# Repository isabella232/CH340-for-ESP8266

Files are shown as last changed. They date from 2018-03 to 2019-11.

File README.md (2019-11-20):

# USB-Serial converter for ESP8266 auto program

DTR, RTS を利用して ESP8266(ESP-WROOM-02) のリセットを制御。Arduino での書き込みを自動化する。

はんだごてでハンダづけでき、わりかしコンパクトなフットプリント。

3.3V 専用。

`J1` ピンはショットキーバリアダイオードを通る分、5V から電圧降下(0.3～0.4V)します。

# ボード

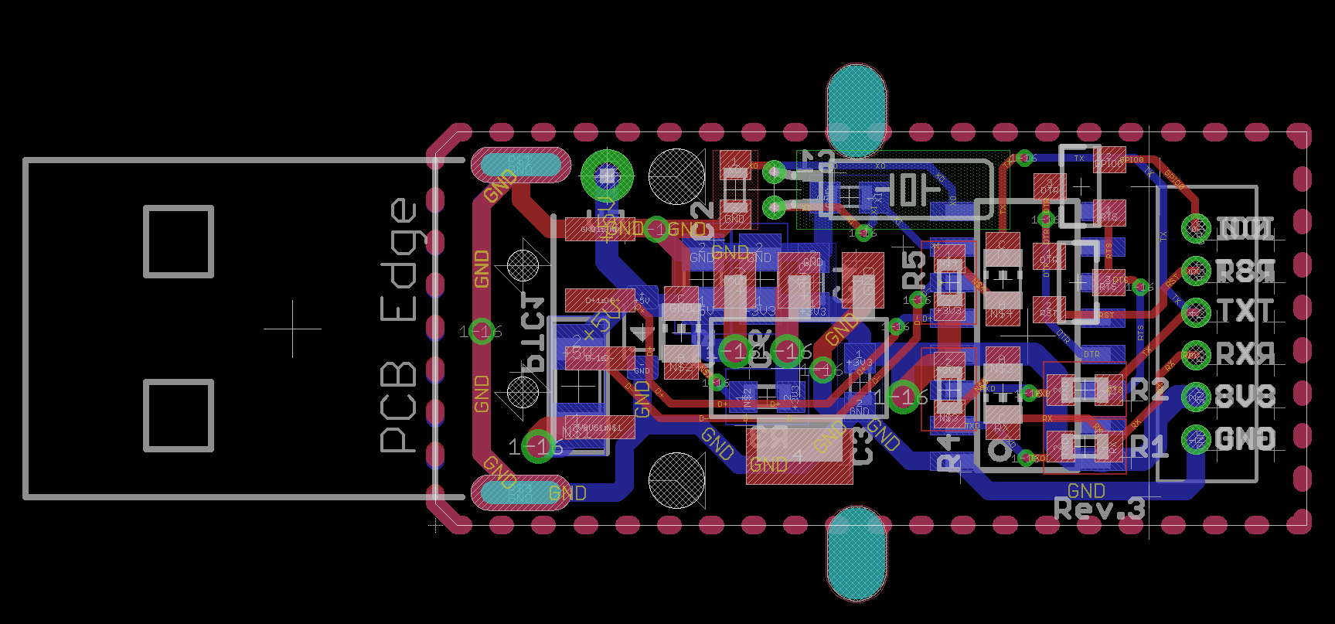
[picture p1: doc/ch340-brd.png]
brd


# 回路図

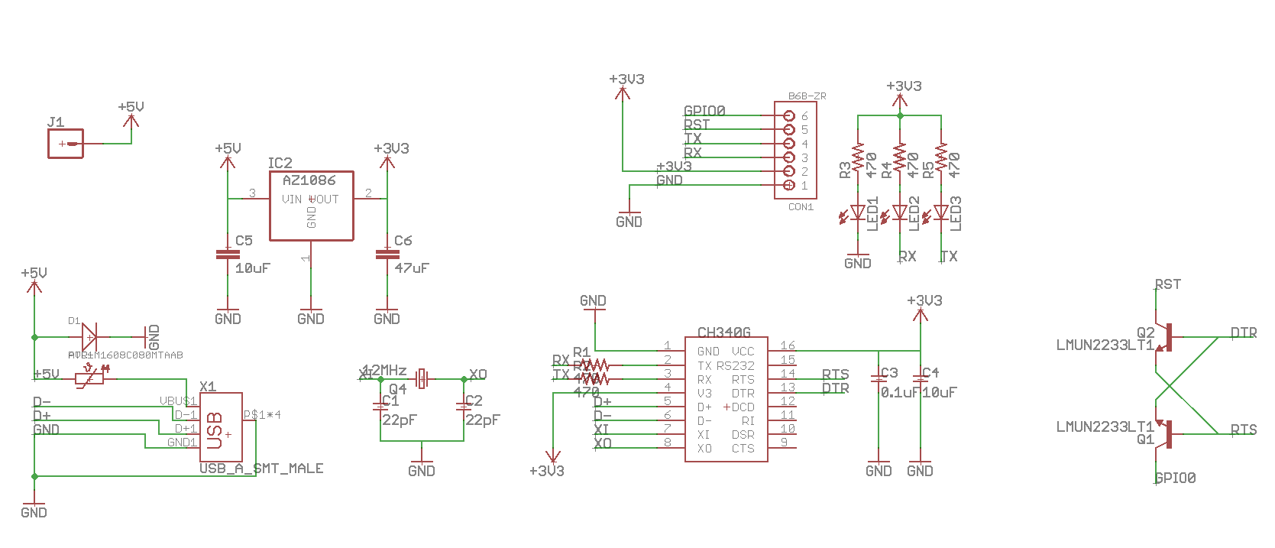
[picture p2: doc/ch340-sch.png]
sch


# 部品表

| 部品番号 | 値 | 部品名 | 入手先 | 備考 |
| --- | --- | --- | --- | --- |
| D1 | 30V1A | ショットキーバリアダイオード RSX101VAM-30TR | 秋月電子 | [I-05951](http://akizukidenshi.com/catalog/g/gI-05951/) |
| PTC1 | 0.75A6V(2012) | リセッタブルフューズ PICOSMDC075S-2 | eBay | https://www.ebay.com/itm/263051781459 |
| X1 | | USBコネクタ(A/オス) UAM-21BK | aitendo  | http://www.aitendo.com/product/16665 |
| C1/C2 | 22pF50V(1608) | 積セラコンデンサ | aitendo  | http://www.aitendo.com/product/6989 |
| Q4 | 12MHz | クリスタル（2x6） | aitendo  | http://www.aitendo.com/product/5028 |
| C3 | 0.1uF50V(1608) | 積セラコンデンサ GRM188F11H104ZA01 | 秋月電子 | [P-13374](http://akizukidenshi.com/catalog/g/gP-13374/) |
| C4/C5 | 10uF25V(2012) | 積セラコンデンサ GRM21BB31E106KA | 秋月電子 | [P-13388](http://akizukidenshi.com/catalog/g/gP-13388/) |
| IC1 | | USB-シリアルコンバータ CH340G | aitendo  | http://www.aitendo.com/product/11576 |
| C6 | 22uF25V(1608) | 積セラコンデンサ GRM21BR61E226ME44 | 秋月電子 | [P-08240](http://akizukidenshi.com/catalog/g/gP-08240/) 47uF がいいかも [mouser](https://www.mouser.jp/Passive-Components/Capacitors/Ceramic-Capacitors/MLCCs-Multilayer-Ceramic-Capacitors/Multilayer-Ceramic-Capacitors-MLCC-SMD-SMT/_/N-bkrdv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) |
| IC2 | 3.3V | レギュレータ AMS1117-3.3 や AZ1086H-3.3 | 秋月電子 | [I-02502](http://akizukidenshi.com/catalog/g/gI-02502/) |
| R1/R2/R3/R4/R5 | 470Ω(1608) | チップ抵抗 | 千石電商 | https://www.sengoku.co.jp/mod/sgk_cart/detail.php?code=EEHD-57GC |
| LED1 | VF=1.9～2.1V(1608) | オレンジ色チップLED | 秋月電子 | [I-06416](http://akizukidenshi.com/catalog/g/gI-06416/) |
| LED2 | VF=1.9～2.1V(1608) | 黄緑色チップLED | 秋月電子 | [I-03980](http://akizukidenshi.com/catalog/g/gI-03980) |
| LED3 | VF=1.9～2.1V(1608) | 赤色チップLED | 秋月電子 | [I-03978](http://akizukidenshi.com/catalog/g/gI-03978) |
| CON1 | ZHコネクタ6ピン | S6B-ZR | 秋月電子 | [C-14164](http://akizukidenshi.com/catalog/g/gC-14164/) ワイヤ直付けでもよいと思います |
| Q1/Q2 | | LMUN2233LT1G | eBay | https://www.ebay.com/itm/262770111020 |
| | E40X18.5X9.6B | USBプラケース | aitendo  | http://www.aitendo.com/product/16537 |

# できあがり

## 表面

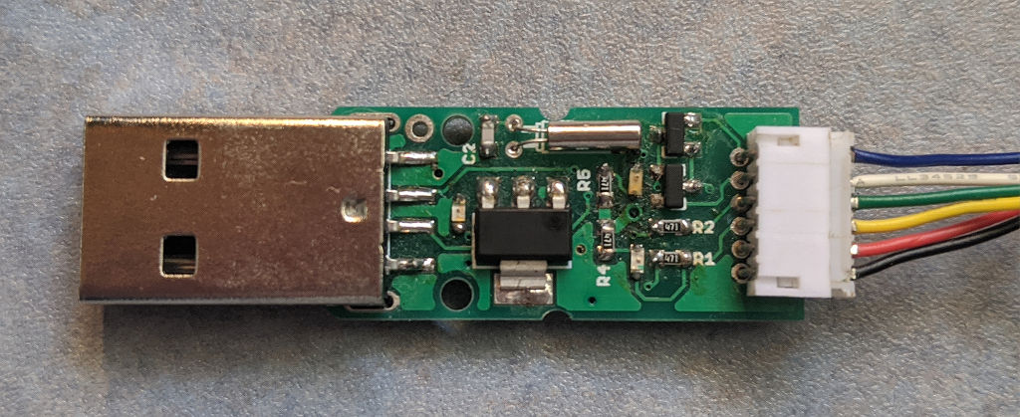
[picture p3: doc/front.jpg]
front


## 裏面

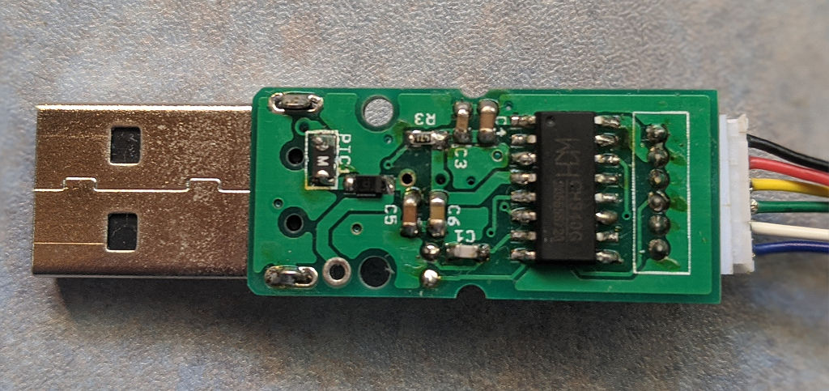
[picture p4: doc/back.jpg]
back


## ケースに入れて接続した状態

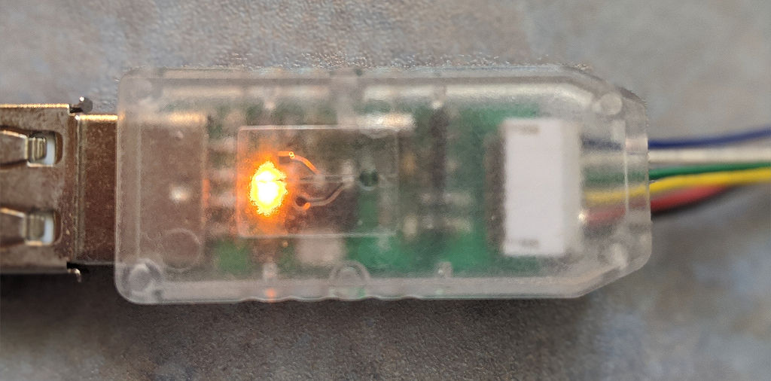
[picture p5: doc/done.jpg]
done


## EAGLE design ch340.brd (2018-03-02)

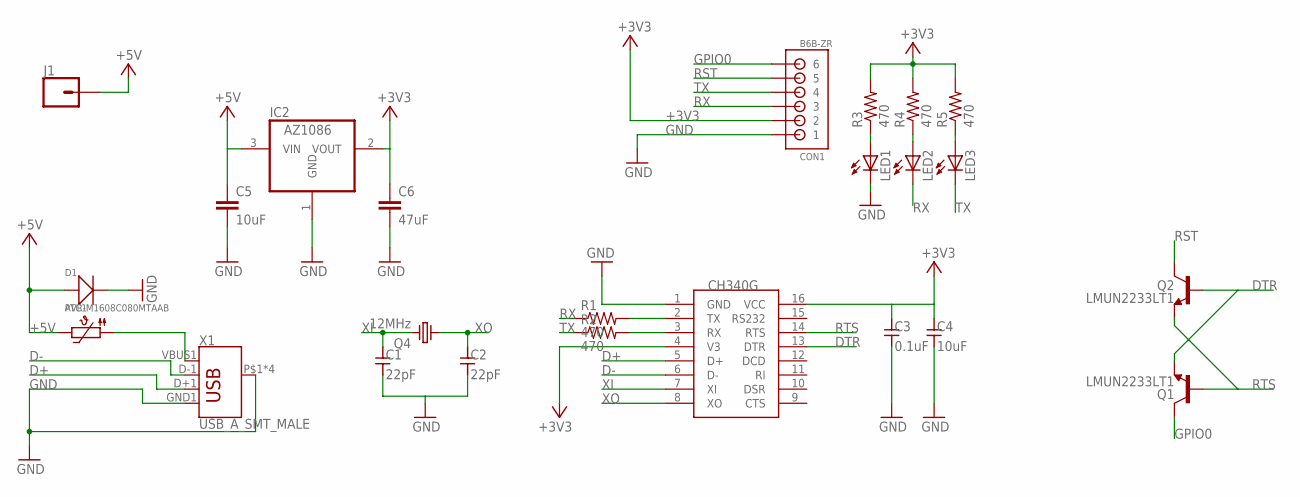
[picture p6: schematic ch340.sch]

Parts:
C1, C2: 22pF; SMD1608
C3: 0.1uF; SMD1608
C4: 10uF; SMD1608
C5: 10uF; C0805
C6: 47uF; C0805
CON1: B6B-ZR
D1: AVR-M1608C080MTAAB; TUMD2
IC2: AZ1086; SOT223
J1: CONN_01PTH_NO_SILK_YES_STOP; 1X01_NO_SILK
LED1, LED2, LED3: LEDCHIP-LED0805; CHIP-LED0805
PTC1: PTC1206; 1206
Q1, Q2: LMUN2233LT1; SOT23-3
Q4: 12MHz; TC26H
R1, R2, R3, R4, R5: 470; R0603
U$1: CH340G; SOIC16
X1: USB_A_SMT_MALE; USB-A-SMT-MALE

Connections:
+3V3: C3.1, C4.1, C6.1, CON1.2, IC2.2 (VOUT), R3.2, R4.2, R5.2, U$1.4 (V3), U$1.16 (VCC)
+5V: C5.1, D1.+, IC2.3 (VIN), J1.1, PTC1.2
D+: U$1.5 (D+), X1.D+1 (D+)
D-: U$1.6 (D-), X1.D-1 (D-)
DTR: Q1.3 (E), Q2.1 (B), U$1.13 (DTR)
GND: C1.2, C2.2, C3.2, C4.2, C5.2, C6.2, CON1.1, D1.-, IC2.1 (GND), LED1.C, U$1.1 (GND), X1.GND1 (GND), X1.P$1 (SHIELD), X1.P$2 (SHIELD), X1.P$3 (SHIELD), X1.P$4 (SHIELD)
GPIO0: CON1.6, Q1.2 (C)
unnamed: PTC1.1, X1.VBUS1 (VBUS)
unnamed: LED1.A, R3.1
unnamed: LED2.A, R4.1
unnamed: LED3.A, R5.1
RST: CON1.5, Q2.2 (C)
RTS: Q1.1 (B), Q2.3 (E), U$1.14 (RTS)
RX: CON1.3, LED2.C, R1.1
RXD: R2.2, U$1.3 (RX)
TX: CON1.4, LED3.C, R2.1
TXD: R1.2, U$1.2 (TX)
XI: C1.1, Q4.2, U$1.7 (XI)
XO: C2.1, Q4.1, U$1.8 (XO)

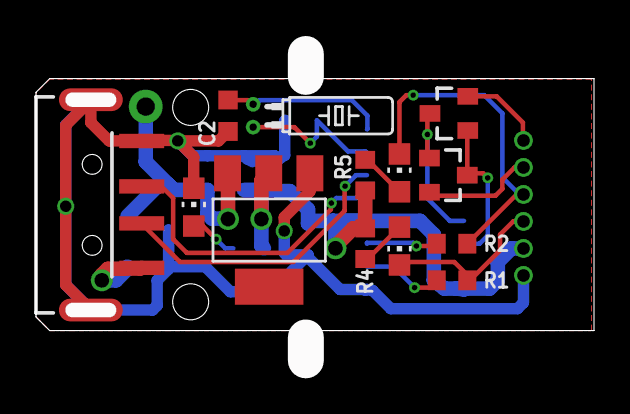
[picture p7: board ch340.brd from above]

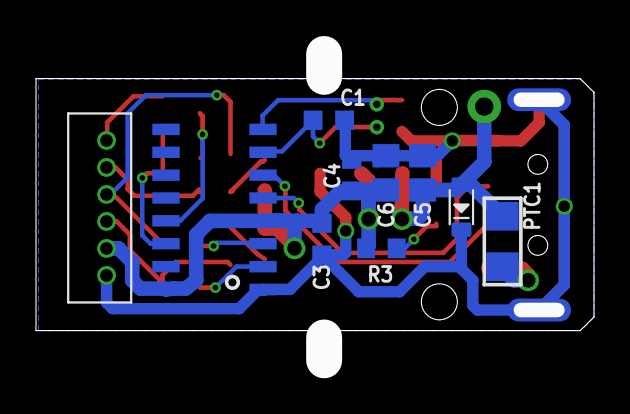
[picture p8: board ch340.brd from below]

Board: 2 copper layers, 31.0 x 14.0 mm, 24 parts (10 on the bottom side), 19 nets.

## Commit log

2017-11-22 CH340G rev.2
    [untitled.GBL, untitled.GBO, untitled.GBP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]
2019-10-16 Deleted gerber file.
    [untitled.GBL, untitled.GBO, untitled.GBP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]
2019-10-16 Renamed eagle file name.
    [ch340.brd, ch340.sch]
2019-11-20 CON1 はワイヤ直付けでもよいと思います
2019-11-20 C6 は 47uF のほうがレギュレータ安定するかも

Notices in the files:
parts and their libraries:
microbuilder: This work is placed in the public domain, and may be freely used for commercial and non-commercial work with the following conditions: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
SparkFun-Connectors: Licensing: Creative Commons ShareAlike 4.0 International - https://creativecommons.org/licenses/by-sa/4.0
